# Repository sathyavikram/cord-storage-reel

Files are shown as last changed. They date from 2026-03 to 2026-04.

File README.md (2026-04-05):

# 🧵 Heavy-Duty Cord Storage Reel (Modular 3D Printable)

A fully parametric, modular, and support-free 3D printable cord storage reel. Designed using FreeCAD's Python API through Constructive Solid Geometry (CSG), this project generates a sturdy 10-piece "flat-pack" assembly that seamlessly snaps together.

🚀 **Download and 3D Print directly from Bambu MakerWorld:** [Heavy-Duty Cord & Wire Storage Reel](https://makerworld.com/en/models/2621094-heavy-duty-cord-wire-storage-reel#profileId-2893059)

At its default scale (`user_scale = 1.0`), the largest printable part fits inside a standard **250x250x250 mm** 3D printer build volume and the assembled reel can hold about **~105 feet of 14/3 wire**.

## ✨ Features
* **Modular, Print-Friendly Parts:** The reel breaks down into simple printable parts (frames, crossbars, split spool, handle, caps) for reliable slicing and straightforward assembly. Included print profiles (`3d-print/` folder) for Bambu and Creality.
* **Fully Parametric:** Just change the `user_scale` variable in `params.py` to proportionally shrink or enlarge the entire assembly. Clearances and tolerances scale automatically.
* **Slip-Fit & Threaded Assembly:** Features center spool alignment, a dedicated handle peg, press-fit crossbars, and retaining threaded parts (fasteners and caps) with mathematically calculated tolerances, including extra clearance (`0.4 mm * scale`) for easy rotation.
* **Auto-Exporting:** Running the scripts generates `.step` and `.stl` files directly into the local `exports/` folder.
* **Rich Media:** See the `media/` folder in the project for visual references, assembly videos, and reference images.

## 📂 File Architecture
The monolithic code has been separated out for easier maintenance and independent part generation:

* `params.py` - Global configuration (scale, dimensions, clearances).
* `part_01_spool_left.py` - Inner rotating spool (Left Half, containing female connector socket).
* `part_01_spool_right.py` - Inner rotating spool (Right Half, containing the stepped axle pin and handle peg).
* `part_02_handle.py` - Hand crank that mounts on the exposed right spool axle peg.
* `part_03_frame.py` - Heavy-duty A-frame structural sides with round crossbar sockets.
* `part_04_crossbars.py` - Cylindrical crossbars that connect the two frame sides.
* `part_04_fasteners.py` - Threaded fasteners with deep screwdriver slots (4.5mm) for structural assembly.
* `part_05_caps.py` - Retaining caps that lock the rotating spool onto the frame.
* `assembly.py` - Master script that imports all parts, constructs the full digital assembly, and exports everything.

## 🚀 How to Generate the 3D Models

### Method 1: Using FreeCAD GUI (Recommended)
1. Open FreeCAD.
2. Open the Python Console (`View` > `Panels` > `Python console`).
3. Open any of the project Python scripts from this folder in the FreeCAD editor so relative imports resolve from the project directory.
4. Execute the script. 
5. The part(s) will be visually rendered in your 3D view, and the `.stl` and `.step` files will be written to the project's `exports/` directory.

### Method 2: Headless CLI (Mac / Linux)
If your terminal's Python environment knows where the FreeCAD `lib` directory is, you can run it directly from your terminal:

```bash
# Example for macOS: Add FreeCAD to your python path and run the assembly
python3 -c "import sys; sys.path.append('/Applications/FreeCAD.app/Contents/Resources/lib'); import assembly; assembly.generate_assembly()"
```

## 📐 Customizing the Scale & Capacity

Want to print a smaller reel for Paracord? Or a massive one for hoses? 
1. Open `params.py`
2. Change the `user_scale` variable (Default is `1.0`).

Estimated capacities at about 70% packing efficiency:

| `user_scale` | Minimum Build Plate Required | Capacity (14/3 Cord, ~9 mm) | Capacity (16/3 Cord, ~8 mm) |
|---|---|---|---|
| 0.50 | 125 mm x 125 mm x 125 mm | **~13 feet** | **~16 feet** |
| 0.75 | 187 mm x 187 mm x 187 mm | **~44 feet** | **~56 feet** |
| **1.00** | **250 mm x 250 mm x 250 mm** | **~105 feet** | **~132 feet** |
| 1.25 | 315 mm x 315 mm x 315 mm | **~205 feet** | **~258 feet** |
| 1.50 | 375 mm x 375 mm x 375 mm | **~353 feet** | **~447 feet** |
| 2.00 | 500 mm x 500 mm x 500 mm | **~838 feet** | **~1,060 feet** |

*At `user_scale = 1.0`, the scaling is tuned so the largest single printable part stays within a 250 mm build envelope. The full digital assembly preview is larger than that because it shows the reel already assembled.*

## 🔧 Assembly Instructions

**Preparation:** Ensure all support material (if any) is removed and the mating surfaces are clean. Test-fit the parts before applying any glue.

1. **Assemble the Spool:** Align and press the **Left Spool Half** (`01_Spool_Left.stl`) and **Right Spool Half** (`01_Spool_Right.stl`) together using the center locking peg.
2. **Mount the Frames:** Slide the **Left Frame** (`03_Frame_Left.stl`) and **Right Frame** (`03_Frame_Right.stl`) onto the protruding axles of the fully assembled spool.
3. **Install the Crossbars:** With the frames seated on the spool axles, press the **3 Crossbars** (`04_Crossbar_Front.stl`, `04_Crossbar_Back.stl`, `04_Crossbar_Top.stl`) into the round sockets between the two frames to lock the main structure together. Add CA glue or epoxy to the crossbar sockets if you want a permanent frame.
4. **Attach the Handle:** Slip the **Handle** (`02_Handle.stl`) outer socket over the smaller, outermost handle peg extending from the **Right Spool** axle. 
5. **Lock it Together:** Snap or glue the **Caps** (`05_Cap_L.stl` and `05_Cap_R.stl`) onto the extremely exposed pin ends (one cap on the far left of the spool axle, one cap holding the handle onto the right peg) to securely retain the moving parts.
## 📸 Gallery & Print Previews

### Images
<details>
<summary>Click to view assembled and printed parts</summary>
<br>















</details>

### Print Plates (Videos)
<details>
<summary>Click to view slicing/print process videos</summary>
<br>

- [Plate 1](media/videos/plate-1.mp4)
- [Plate 3](media/videos/plate-3.mp4)
- [Plate 4](media/videos/plate-4.mp4)
- [Plate 5](media/videos/plate-5.mp4)

*(Note: GitHub natively supports playing embedded .mp4 files if you click the links!)*
</details>

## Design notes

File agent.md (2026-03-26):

 review assembly file and make sure all parts are added and final render does not have any defects floating objects and easy to 3D print. do not
  make any code changes. just give me defect report. Use visual validations using mcp tool

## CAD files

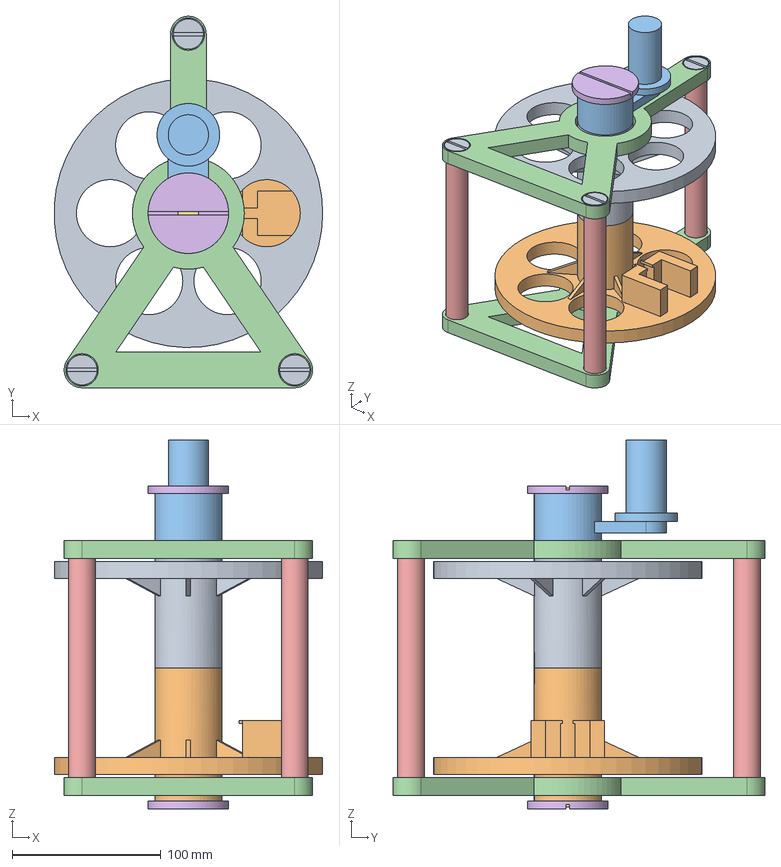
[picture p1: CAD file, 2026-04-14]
exports/assembly.step
180.6 x 250.0 x 248.2 mm
Spool Right
Spool Left
Handle
Frame Right
Frame Left
Crossbar Front
Crossbar Back
Crossbar Top
Cap Left
Cap Right (Handle)
Frame Bolt R1
Frame Bolt R2
Frame Bolt R3
Frame Bolt L1
Frame Bolt L2
Frame Bolt L3

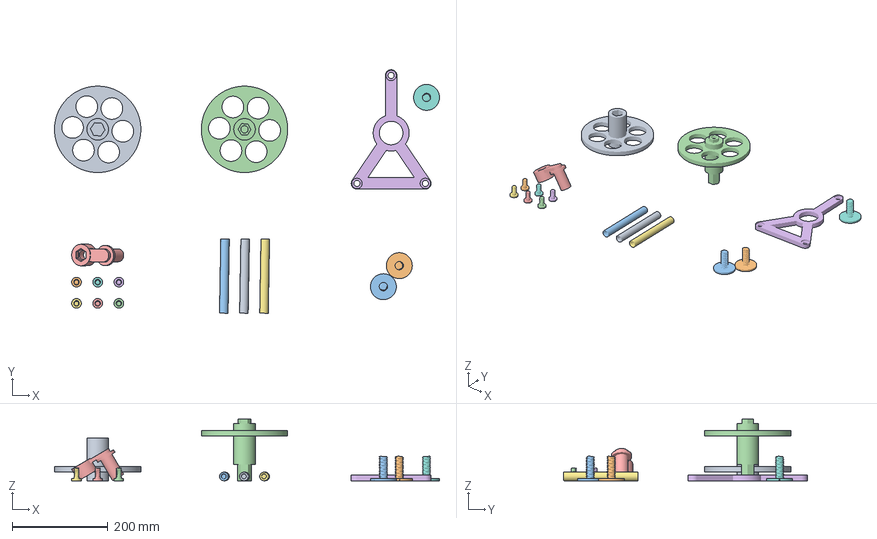
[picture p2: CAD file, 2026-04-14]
3d-print/cord-storage-reel-bambu.3mf
805.5 x 509.7 x 128.8 mm
part_01_spool_left.stl
part_05_caps.stl x 3
part_01_spool_right.stl
part_02_handle.stl
part_04_fasteners.stl x 6
part_04_crossbars.stl x 3
part_03_frame.stl

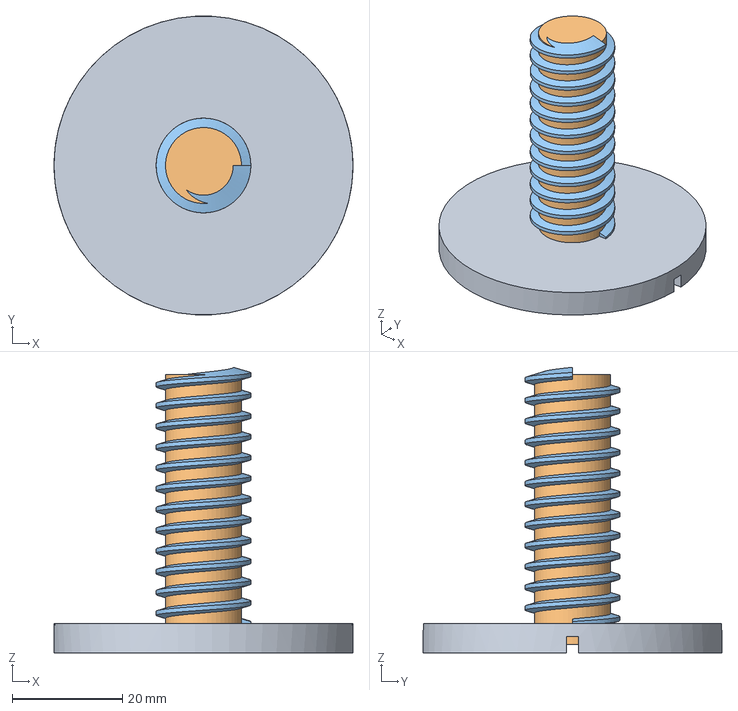
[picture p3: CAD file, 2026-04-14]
exports/part_05_caps.step
54.2 x 54.1 x 51.8 mm

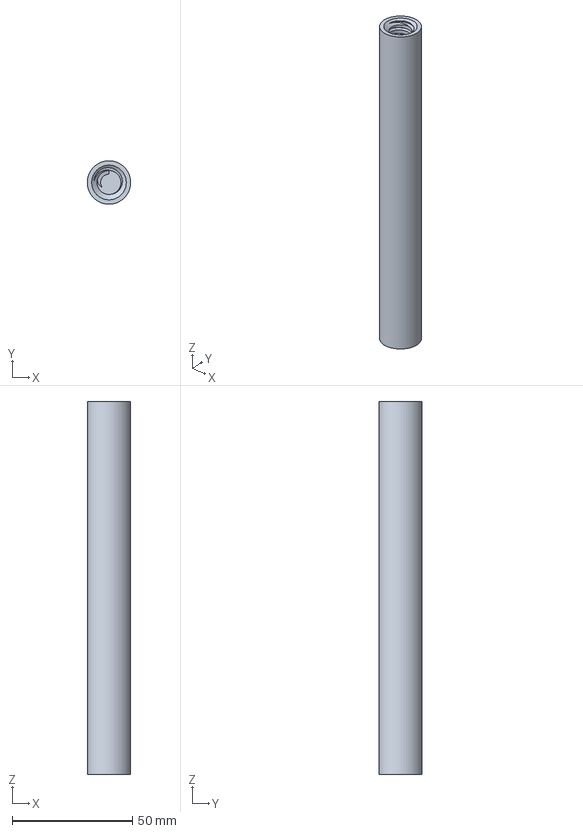
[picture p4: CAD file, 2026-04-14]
exports/part_04_crossbars.step
18.1 x 18.1 x 155.1 mm

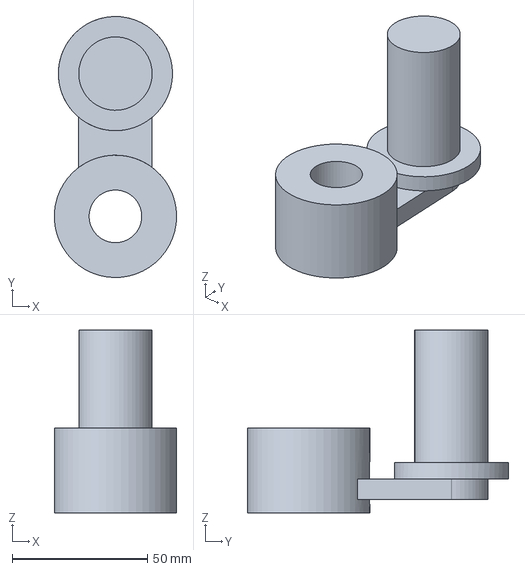
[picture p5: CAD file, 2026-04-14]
exports/part_02_handle.step
45.1 x 96.4 x 67.5 mm

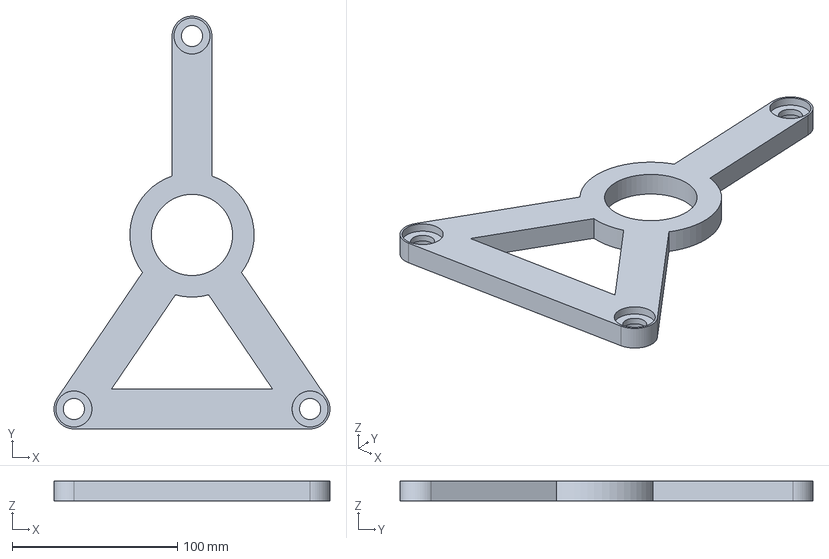
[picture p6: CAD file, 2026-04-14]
exports/part_03_frame.step
167.2 x 250.0 x 12.0 mm

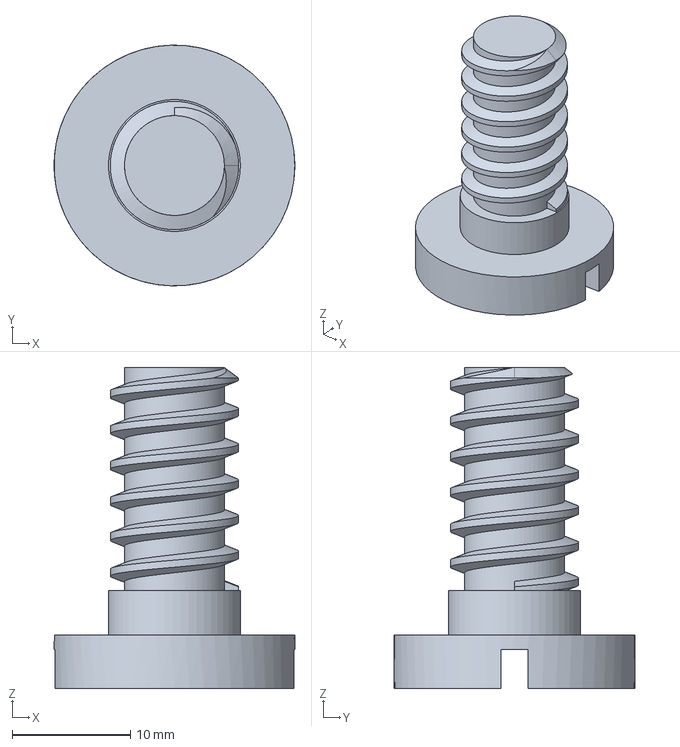
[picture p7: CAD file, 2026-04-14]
exports/part_04_fasteners.step
20.3 x 20.3 x 27.1 mm

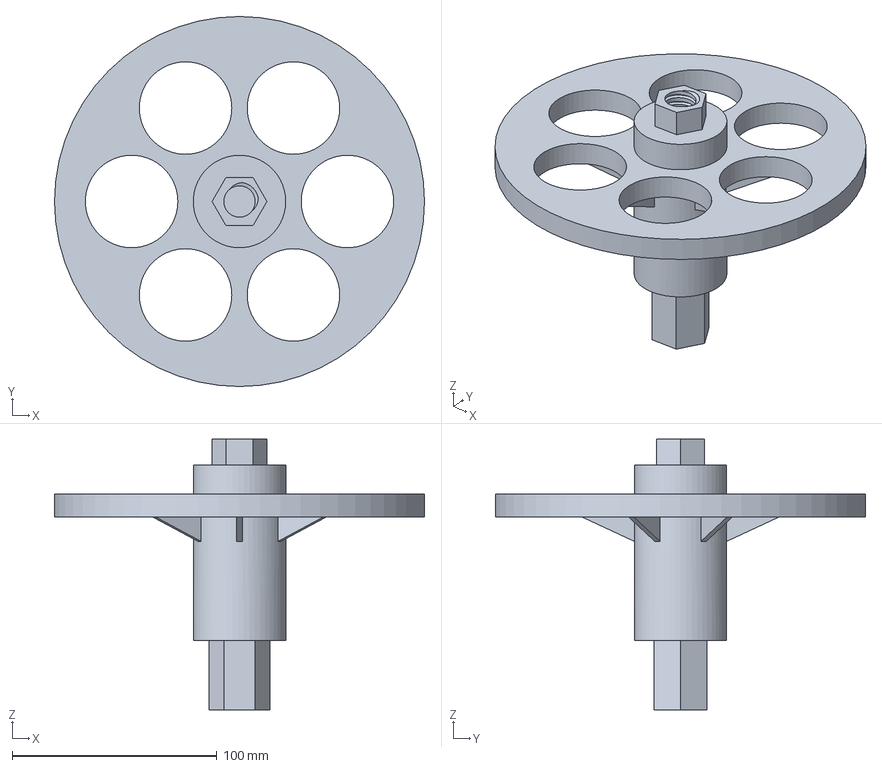
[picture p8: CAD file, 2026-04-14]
exports/part_01_spool_right.step
180.7 x 180.7 x 132.3 mm

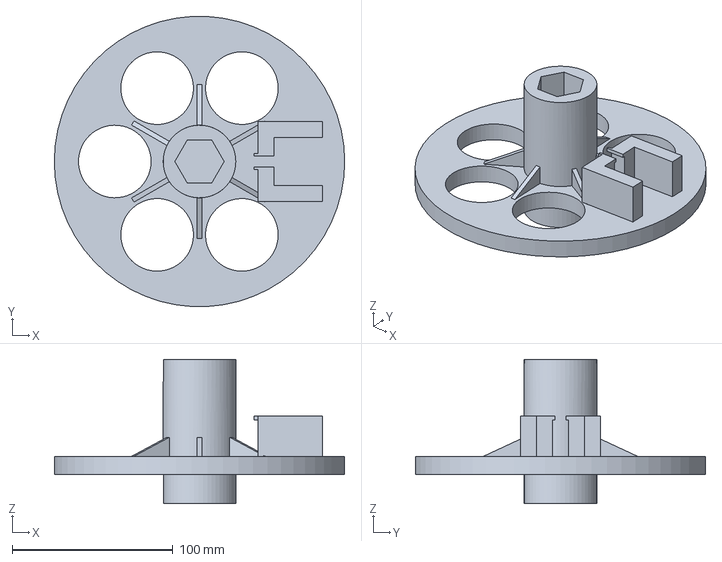
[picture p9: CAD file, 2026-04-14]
exports/part_01_spool_left.step
180.7 x 180.5 x 89.6 mm

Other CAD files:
3d/cord-storage-reel-bambu.3mf
exports/part_02_handle.stl
exports/part_03_frame.stl

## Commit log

2026-03-18 Update reel_logic.py for 150 ft cord, adjust stand gaps and fillets
    [flange-axle-handle.step]
2026-03-18 Refactor reel_logic.py to use user_scale and scale proportionally for 150ft 14/3 cord on 350mm build plate
    [flange-axle-handle.step]
2026-03-19 Complete redesign: modular 10-piece flat-pack assembly with semi-rectangular frame
2026-03-19 Refactor: Split monolith into modular part files
    [00_Full_Assembly_Preview.step, 01_Right_Spool_Half.stl, 02_Left_Spool_Half.stl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]
2026-03-19 Update scale to exactly bound to 250x250x250 when user_scale=1.0 and split spool
    [00_Full_Assembly_Preview.step, 01_Right_Spool_Half.stl, 01_Spool_Left.step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]
2026-03-19 docs: format scale chart into table
    [00_Full_Assembly_Preview.step, 01_Right_Spool_Half.stl, 01_Spool_Left.step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]
2026-03-19 docs: append 16/3 gauge cord capacities to README table
2026-03-19 feat: complete CAD parameters, spool separation, and documentation
    [02_Handle.step, 02_Handle.stl, 03_Frame_Left.step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]
2026-03-19 fix: redesign handle as an axle crank arm outside the right frame ring
    [00_Full_Assembly_Preview.step, 01_Right_Spool_Half.stl, 02_Handle.step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]
2026-03-20 Fix joint gaps, correct handle standoff, organize test files, and update assembly export path
    [00_Full_Assembly_Preview.step, 01_Right_Spool_Half.stl, 01_Spool_Left.stl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]
2026-03-20 Add new generated STL and step files along with 3mf cut files
    [00_Full_Assembly_Preview.step, 01_Spool_Left.step, 01_Spool_Left.stl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]
2026-03-20 Move bambu 3mf to exports folder
    [cord-storage-reel-bambu-250mm.3mf]
2026-03-22 Update Bambu 250mm 3MF export
    [cord-storage-reel-bambu-250mm.3mf]
2026-03-22 Refactor into snap-fit joints, increase handle size, and remove temporary files
    [00_Full_Assembly_Preview.step, 01_Spool_Left.step, 01_Spool_Left.stl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]
2026-03-22 feat: updated assembly outputs, added 5mm gap on left cap, and flattened export dir
    [00_Full_Assembly_Preview.step, 01_Spool_Left.step, 01_Spool_Right.step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]
2026-03-23 Update part_05_caps, add render script, and update model exports
    [00_Full_Assembly_Preview.step, 01_Spool_Left.step, 01_Spool_Right.step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]
2026-03-25 Update model: fix boolean hangs via makeCompound on center bolt, convert hex heads to flathead slots on fasteners, clean up files
2026-03-25 Stop tracking exports folder and ignore it
    [00_Full_Assembly_Preview.step, 01_Spool_Left.step, 01_Spool_Right.step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]
2026-03-26 Adjust spool to frame clearance to ~2mm and decouple pins
2026-03-27 Fix handle diameter to match spool and increase arm width
2026-03-27 Fix thread phase mismatch causing overlaps
2026-03-27 Adjust left/right spool split: 50% hex pocket, 50% threaded hole
2026-03-27 Add export_all script to automate STL and STEP generation
2026-03-29 Refactor part exports, assembly logic, and flatten project structure
    - Moved part scripts to root and flattened directory structure
    - Standardized step and stl file generation to export into a central exports/ directory
    - Unified part_03_frame and part_04_crossbars to generate single, identical/generic geometric components instead of duplicates
    - Standardized all export files to exactly match their generator script name
    - Overhauled assembly scripts (assembly_main.py, assembly_spool.py) to dynamically construct full previews using placement matrices
    - Scripts auto-generate missing dependency part step files on-the-fly before importing them
2026-03-29 Rename assembly outputs to match python script names
2026-03-29 Update assembly scripts to generate corresponding STL files
2026-03-29 Fix python GUI module cache by reloading part modules in assembly scripts
2026-03-29 Add new assembly file for left spool, right spool, and handle
2026-03-29 Update mechanical spacing parameters and add all fasteners to main assembly
2026-03-29 Export assembly_main as multi-body STEP file so components are individually selectable in Fusion 360
2026-03-30 Fix assembly blank export and adjust fastener depths
2026-03-30 Optimize assembly_main to skip automatic part generation when STEP files exist
2026-04-02 Increase center bolt clearance to 0.6
2026-04-03 Fix cap hole threading on spool and reduce hex depth overlap
2026-04-03 Update 3D print 3mf file
2026-04-05 Increase fastener screwdriver slot depth
2026-04-05 Update 3d print profiles and media
    [cord-storage-reel-bambu.3mf]
2026-04-05 Update gitignore and add exports directory (excluding large assembly.stl)
    [assembly.step, part_01_spool_left.step, part_01_spool_right.step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]
2026-04-05 Update README with latest 3D print profiles, fasteners, media, and features
2026-04-08 Update Bambu 3mf print profile and add new product images
    [cord-storage-reel-bambu.3mf]
2026-04-11 Update spool geometries, add exports, and add test sweeps/grooves
    [assembly.step, cord-storage-reel-bambu.3mf, final_good_cut.step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]
2026-04-11 Clean up unneeded test files and intermediate geometry files
    [final_good_cut.step, final_nofrenet.step, final_spool.step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]
2026-04-14 feat: add wire retainer slot to left spool, increase handle standoff and thread clearance
    [assembly.step, cord-storage-reel-bambu.3mf, part_01_spool_left.step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]
